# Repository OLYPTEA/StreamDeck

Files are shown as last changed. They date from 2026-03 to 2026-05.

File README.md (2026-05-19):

# KORE DECK

<p align="center">
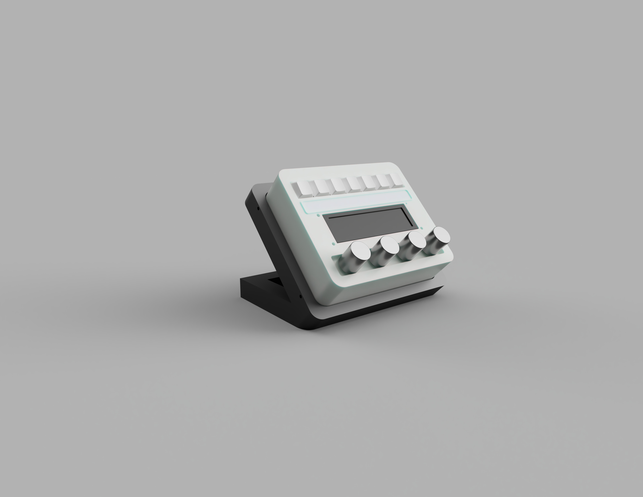
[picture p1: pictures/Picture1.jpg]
  
</p>

<p align="center">
  
  
  
</p>

<h3 align="center">
Un Hub de Control Modulaire pour PC et Robotique/A Modular Stream Deck & Robotics Control Hub (cf : Robotic_Arm)
</h3>

---

##  Video de présentation/Cinematic Demo

https://github.com/user-attachments/assets/3f7520e6-ee07-4d92-a84f-97e8f2b0d568

<p align="center">
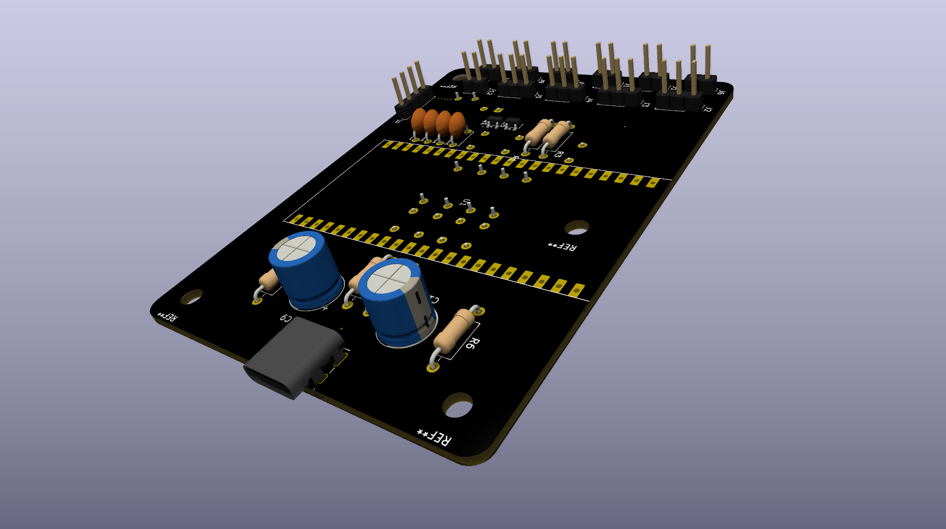
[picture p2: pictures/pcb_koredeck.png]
  
</p>

---

## Description

Ce projet est un **Stream Deck DIY** développé dans le but d'être modulaire.  
Conçu autour d'un **ESP32-S3**, il permet de piloter des raccourcis PC, de monitorer des ressources, mais aussi de servir de **Hub de contrôle** pour des périphériques externes (bras robotique, capteurs) via un port d'extension dédié.

This project is a **DIY Stream Deck** designed to be modular.  
Built around an **ESP32-S3**, it allows you to control PC shortcuts, monitor system resources, and serve as a **control hub** for external devices (such as robotic arms and sensors) via a dedicated expansion port.

---

# Spécifications Matérielles

| Composant | Détails |
| :--- | :--- |
| **Microcontrôleur** | ESP32-S3 DevKit N16R8 (16MB Flash / 8MB PSRAM) |
| **Écran** | DWIN HMI 960x240 (Interface UART, protocole DGUS II) |
| **Capteurs** | 7x Switchs mécaniques (Cherry MX) + 4x Potentiomètres analogiques |
| **Alimentation** | USB-C natif (Compatible **Thunderbolt** pour forte puissance) |
| **Modularité** | Boîtier CAO avec pied indépendant et port d'extension I2C |

---

# Points Forts du Projet

## 1. Conception Modulaire (CAO)

Le boîtier a été conçu sous **Fusion 360** avec une approche modulaire :

- **Pied indépendant :**  
  Permet d'adapter différents angles ou supports (pince de bureau, bras articulé).

- **Port d'extension :**  
  Sortie des ports non-utilisés (SDA/SCL, 5V, GND) sur le côté pour connecter des modules sans ouvrir le boîtier.

- **Modularité du Software/Firmware**
  Pensé dans le but d'être mobile et évolutif (rajout facile à intégrer)

The Case was designed in **Fusion 360** using a modular approach:

- **Detachable stand:**  
  Allows for different angles or mounts (desk clamp, articulated arm).

- **Expansion port:**  
  Unused ports (SDA/SCL, 5V, GND) are routed to the side to connect modules without opening the enclosure.

- **Software/Firmware Modularity**
  Designed to be portable and scalable (easy to integrate new features)

---

## 2. Hub Robotique/Robotics Hub

Grâce au port d'extension, le Stream Deck peut piloter un **bras robotique** (servomoteurs) via un driver **PCA9685**.

- **Mapping dynamique :**  
  Les potentiomètres contrôlent directement les angles des servos lorsque le profil `Robot` est sélectionné.

- **Affichage temps réel :**  
  L'écran DWIN affiche l'état et la position de chaque articulation.

Thanks to the expansion port, the Stream Deck can control a **robotic arm** (servo motors) via a **PCA9685** driver.

- **Dynamic mapping:**  
  The potentiometers directly control the servo angles when the `Robot` profile is selected.

- **Real-time display:**  
  The DWIN screen displays the status and position of each joint.

---

## 3. Gestion de l'Énergie/Energy Management

Optimisation pour le **Thunderbolt** :

- Alimentation directe des périphériques (Écran, Servos) via la ligne **5V/Vin** pour préserver le régulateur interne de l'ESP32.

- Filtrage matériel par condensateurs (`470µF` → `1000µF`) pour stabiliser les pics de courant des moteurs.

Optimization for **Thunderbolt**:

- Direct power supply to peripherals (display, servos) via the **5V/Vin** line to preserve the ESP32’s internal voltage regulator.

- Hardware filtering using capacitors (`470µF` → `1000µF`) to stabilize motor current spikes.

---

# Schéma de Câblage (Résumé)/Wiring Diagram (Summary)

Le projet utilise des techniques de filtrage pour garantir la précision des lectures analogiques :

- **Potentiomètres :**  
  Condensateurs de `100nF` pour le lissage du signal.

- **Boutons :**  
  Condensateurs de `10nF` pour le debounce matériel.

- **Communication Écran :**  
  Liaison série directe (`3.3V TTL`) sur `Rx2/Tx2`.

The project uses filtering techniques to ensure the accuracy of analog readings:

- **Potentiometers:**  
  `100nF` capacitors for signal smoothing.

- **Buttons:**  
  `10nF` capacitors for hardware debouncing.

- **Display communication:**  
  Direct serial connection (`3.3V TTL`) on `Rx2/Tx2`.

---

# Structure du Dépôt/Structure of the Repository

```text
├── Hardware/           # Fichiers STEP/STL (Fusion 360)/STEP/STL files (Fusion 360)
├── Firmware/           # Code source ESP32 (Arduino IDE / PlatformIO)/ESP32 source code (Arduino IDE / PlatformIO)
├── DWIN_Project/       # Fichiers de configuration DGUS II (Interface graphique)/DGUS II Configuration Files (Graphical Interface)
├── Scripts_PC/         # Script de détection d'application (Python/C#)/Application detection script (Python/C#)
└── Assets/             # Icônes, vidéos et ressources graphiques/Icons, videos, and graphic resources
```

---

# Roadmap

- [ ] Interface UI avancée/Advanced UI (check)
- [ ] Gestion multi-profils/Multi-profile management (check)
- [ ] Intégration MQTT/MQTT integration
- [ ] Contrôle robotique avancé/Advanced robotics control
- [ ] Support Wi-Fi / Bluetooth/Wi-Fi / Bluetooth support
- [ ] Intégration Home Assistant/Home Assistant integration

---

# Technologies Utilisées/Technologies Used

- **ESP32-S3**
- **DGUS II / DWIN HMI**
- **Fusion 360**
- **Arduino / PlatformIO**
- **Python / C++**
- **I2C / UART**
- **KicKad**

---

# Auteur/Author

Projet conçu et développé par **OLYPTEA** (Sacha Gibert).

Project designed and developed by **OLYPTEA** (Sacha Gibert).

GitHub :  
https://github.com/OLYPTEA

---

Mention à Andrei Doncescu : https://homepages.laas.fr/adoncesc/SystemEmbed/Filtrage.pdf, 
          Random Nerds Tutorial : https://randomnerdtutorials.com/esp32-save-data-permanently-preferences/, 
          cppreference.com : https://en.cppreference.com/cpp/language/static_cast,
          Peng Zhihui : https://github.com/peng-zhihui/HoloCubic <3,
          STMicroelectronics — AN2834 : https://www.st.com/resource/en/application_note/cd00211314-how-to-optimize-the-adc-accuracy-in-the-stm32-mcus-stmicroelectronics.pdf,
          Claude code : Débogage,
          Espressif Systems : https://documentation.espressif.com/esp32-s3_datasheet_en.pdf,
          Tauri : http://github.com/tauri-apps/tauri/blob/dev/ARCHITECTURE.md,
                  https://github.com/tauri-apps/awesome-tauri

---

Merci d'avoir pris le temps de regarder le projet

Thank you for taking the time to look at the project

---

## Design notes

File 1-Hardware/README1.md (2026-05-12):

# Avertissement / Warning :

## FR : L'empreinte de l'ESP32 utilisée dans la schématique n'est pas la bonne, il s'agit de l'empreinte d'un ESP32-S3-WROOM-1 (utilisé pour des raisons de praticité dans le logiciel) -> Impact sur les GPIO utilisés : RX0 = GPIO 16 et TX0 = GPIO 17 , Switchs (1/7) =  GpIO 09, GPIO 08, GPIO 14, GPIO 13, GPIO 15, GPIO 12, GPIO 11 (Correct dans le schéma), Potentiomètres = GPIO 04, GPIO 05, GPIO 06, GPIO 07

## ENG : The ESP32 footprint used in the schematic is incorrect, it's the footprint of an ESP32-S3-WROOM-1 (used for convenience in the software). This impacts the GPIO pins used : RX0 = GPIO 16 and TX0 = GPIO 17, Switches (1/7) = GPIO 9, GPIO 8, GPIO 14, GPIO 13, GPIO 15, GPIO 12, GPIO 11 (Correct in the schematic), Potentiometers = GPIO 4, GPIO 5, GPIO 6, GPIO 7

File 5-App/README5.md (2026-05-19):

# Kore Deck — Application Desktop

Application Tauri 2 (Rust + WebView2) qui sert d'interface de contrôle pour Kore Deck.
Elle se connecte à l'agent Python via WebSocket et affiche en temps réel les données système,
les actions boutons et les valeurs potentiomètres.

---

## Stack technique

| Couche | Technologie | Version |
|---|---|---|
| Shell natif | Tauri | 2.x |
| Backend Rust | Tauri core + serialport + env_logger | — |
| Frontend | React + TypeScript | 19 / 5.x |
| Bundler | Vite | 7.x |
| State management | Zustand (persist → localStorage) | 5.x |
| Transport | WebSocket `ws://localhost:8765` | — |
| Design system | Carbon (custom CSS, palette `#0C0C0E`) | — |

---

## Prérequis

| Outil | Version minimale | Vérification |
|---|---|---|
| Node.js | 20 LTS | `node -v` |
| npm | 10+ | `npm -v` |
| Rust (stable) | 1.82 | `rustc --version` |
| WebView2 Runtime | — | préinstallé sur Win 11 , sinon [télécharger](https://developer.microsoft.com/fr-fr/microsoft-edge/webview2/) |
| Python | 3.10+ | `python --version` |

> **Windows uniquement.** Le binaire final est un `.exe` / `.msi` ciblant Windows 10/11 x64.

---

## Installation des dépendances

```bash
# Depuis le dossier Kore Deck/KoreDeck_App/
npm install
```

Cargo télécharge automatiquement les crates Rust au premier build.

---

## Développement

### 1. Mode Dev (si vous voulez bricoler :D )

```bash
# Terminal 1 — app Tauri 
npm run tauri dev
```

Une fenêtre s'ouvre avec le hot-reload Vite actif.
Le simulateur de données (`useDevSimulator`) s'active automatiquement **uniquement** en mode dev
(`import.meta.env.DEV`) : il injecte des stats CPU/RAM fictives toutes les secondes,
ce code est absent du build final.

### 2. Lancer l'agent Python en parallèle (optionnel en dev)

```bash
# Terminal 2 — depuis Software/
python agent.py --port COM3 --baud 115200
```

Sans l'agent, le simulateur dev prend le relais pour les métriques.
Avec l'agent, la connexion WebSocket `ws://localhost:8765` est établie automatiquement.

---

## Build de production

```bash
npm run tauri build
```

Durée typique : 4–8 min (première fois, Cargo compile tout).

### Artefacts générés

| Fichier | Chemin |
|---|---|
| Exécutable portable | `src-tauri/target/release/kore-deck.exe` |
| Installateur MSI | `src-tauri/target/release/bundle/msi/kore-deck_*.msi` |
| Installateur NSIS | `src-tauri/target/release/bundle/nsis/kore-deck_*-setup.exe` |

---

## Architecture du code frontend

```
src/
├── App.tsx               # Routage principal + hook useDevSimulator (dev only)
├── index.css             # Design system Carbon — variables CSS globales
│
├── components/
│   ├── Sidebar.tsx       # Navigation latérale + indicateur de connexion
│   ├── Dashboard.tsx     # Vue HOME — CPU, RAM, pistes audio
│   ├── Settings.tsx      # Configuration port série, WebSocket, reconnexion
│   └── Profiles.tsx      # Sélection de catégorie (HOME / MAKING / FOCUS / GAME)
│
├── hooks/
│   └── useSerial.ts      # Connexion WebSocket, parsing trames, reconnexion auto
│
└── store/
    └── useStore.ts       # Zustand store — état global + persist localStorage
```

---

## Flux de données

```
ESP32-S3 (UART 115200)
    │  trames texte : "POT:VOL_MASTER:87", "ACTION:MUTE", "CAT:2"
    ▼
Agent Python  (Software/agent.py)
    │  WebSocket JSON  ws://localhost:8765
    ▼
useSerial.ts  (hook React)
    │  messages parsés → dispatch Zustand
    ▼
Zustand store  (useStore.ts)
    │  état réactif : stats, connexion, settings
    ▼
Composants React  (Dashboard, Sidebar, Settings, Profiles)
```

---

## Commandes Tauri (Rust → frontend)

| Commande | Description |
|---|---|
| `list_serial_ports` | Renvoie la liste des ports COM disponibles |
| `open_serial` | Ouvre un port série (port, baud) |
| `close_serial` | Ferme le port série actif |
| `send_serial` | Envoie une trame brute sur le port ouvert |
| `read_serial` | Lit les octets disponibles |
| `get_app_version` | Renvoie la version depuis `Cargo.toml` |
| `show_in_explorer` | Ouvre l'explorateur sur un chemin donné |
| `get_log_path` | Renvoie le chemin du fichier de log actif |

---

## Paramètres de connexion par défaut

| Paramètre | Valeur |
|---|---|
| Port série | `COM3` |
| Baud rate | `115200` |
| WebSocket | `ws://localhost:8765` |
| Reconnexion auto | activée, délai 3 s |
| Timeout PC (firmware) | 5 000 ms |

Ces valeurs sont modifiables dans l'onglet **Settings** et persistent au redémarrage.

---

## Persistance des données

L'état de l'application est sauvegardé via Zustand `persist` dans le `localStorage` du WebView2.

| Clé localStorage | `kore-deck-store` |
|---|---|
| Chemin physique (Windows) | `%APPDATA%\com.koredeck.deck\EBWebView\Default\Local Storage\` |
| Contenu | settings (port, baud, ws URL), catégorie active, préférences UI |

Pour réinitialiser : supprimer la clé dans les DevTools (F12 → Application → Local Storage).

---

## Lancer les DevTools en production

La fenêtre Tauri expose les DevTools uniquement en mode dev.
Pour déboguer un build release, ajouter temporairement dans `tauri.conf.json` :

```json
"app": {
  "windows": [{ "devtools": true }]
}
```

---

## Régénérer depuis zéro (environnement vierge)

```bash
# 1. Installer Rust
curl --proto '=https' --tlsv1.2 -sSf https://sh.rustup.rs | sh   # Linux/macOS
# ou : https://rustup.rs  (Windows)

# 2. Installer les cibles Tauri
cargo install tauri-cli --version "^2"

# 3. Installer Node.js 20 LTS : https://nodejs.org

# 4. Cloner le projet
git clone <repo-url>
cd Kore Deck/5-App

# 5. Dépendances Node
npm install

# 6. Dev
npm run tauri dev

# 7. Production
npm run tauri build
```

---

## Dépannage

| Symptôme | Cause probable | Solution |
|---|---|---|
| Fenêtre blanche au démarrage | WebView2 absent | Installer [WebView2 Runtime](https://developer.microsoft.com/fr-fr/microsoft-edge/webview2/) |
| `error: linker 'link.exe' not found` | MSVC non installé | Installer **Build Tools for Visual Studio 2022** avec la charge « Développement Desktop C++ » |
| WebSocket ne se connecte pas | Agent Python non démarré | Lancer `python agent.py` en parallèle |
| Port COM introuvable | Pilote USB absent | Installer le pilote CP210x ou CH340 selon la puce USB-UART de la carte |
| `SERIAL_BUFFER_SIZE` overflow (firmware) | Trame corrompue trop longue | Vérifier câble USB, réduire longueur trame, redémarrer ESP32 |

**Bonne utilisation à tous, si vous trouvez un bug ou des trucs à optimiser n'hesitez pas à demander un pull request, HF :D**

---

Auteur : OLYPTEA

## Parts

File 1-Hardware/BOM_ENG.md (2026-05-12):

# BOM - ESP32-S3 Stream Deck / Control Panel

## Microcontroller
| Quantity | Component | Reference |
|---|---|---|
| 1 | ESP32-S3 DevKit | ESP32-S3 DevKit N16R8 |

---

## User Interface

### Potentiometers
| Quantity | Component | Value |
|---|---|---|
| 4 | Linear Potentiometer | B10K |

### Mechanical Switches
| Quantity | Component | Reference |
|---|---|---|
| 7 | Mechanical Keyboard Switch | Cherry MX |

### Display
| Quantity | Component | Reference |
|---|---|---|
| 1 | DWIN Display | DMG96240C037_03W |

---

## Transistors
| Quantity | Component | Reference |
|---|---|---|
| 2 | N-Channel MOSFET | BSS138 |

---

## Capacitors
| Quantity | Component | Value |
|---|---|---|
| 7 | Ceramic Capacitor | 10nF |
| 5 | Ceramic Capacitor | 100nF |
| 1 | Electrolytic Capacitor | 10µF |

---

## Resistors
| Quantity | Component | Value |
|---|---|---|
| 4 | Resistor | 10kΩ |
| 4 | Resistor | 1kΩ |
| 2 | Resistor | 5.1kΩ |

---

## Connectivity
| Quantity | Component | Reference |
|---|---|---|
| 1 | USB Type-C Connector | USB-C Port |

---

# Notes
- The 5.1kΩ resistors are used for USB-C CC1/CC2 configuration.
- The 100nF capacitors are used for power supply decoupling.
- The BSS138 MOSFETs are be used for logic level shifting (5V to 3.3V).
- The DWIN display generally communicates with the ESP32-S3 through UART.

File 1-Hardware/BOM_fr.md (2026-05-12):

# BOM - ESP32-S3 Stream Deck / Control Panel

## Microcontrôleur
| Quantité | Composant | Référence |
|---|---|---|
| 1 | ESP32-S3 DevKit | ESP32-S3 DevKit N16R8 |

---

## Interface utilisateur

### Potentiomètres
| Quantité | Composant | Valeur |
|---|---|---|
| 4 | Potentiomètre linéaire | B10K |

### Switchs mécaniques
| Quantité | Composant | Référence |
|---|---|---|
| 7 | Switch mécanique Cherry MX | Cherry MX |

### Écran
| Quantité | Composant | Référence |
|---|---|---|
| 1 | Écran DWIN | DMG96240C037_03W |

---

## Transistors
| Quantité | Composant | Référence |
|---|---|---|
| 2 | MOSFET N-Channel | BSS138 |

---

## Condensateurs
| Quantité | Composant | Valeur |
|---|---|---|
| 7 | Condensateur céramique | 10nF |
| 5 | Condensateur céramique | 100nF |
| 1 | Condensateur électrolytique | 10µF |

---

## Résistances
| Quantité | Composant | Valeur |
|---|---|---|
| 4 | Résistance | 10kΩ |
| 4 | Résistance | 1kΩ |
| 2 | Résistance | 5.1kΩ |

---

## Connectique
| Quantité | Composant | Référence |
|---|---|---|
| 1 | Connecteur USB Type-C | USB-C Port |

---

# Notes
- Les résistances 5.1kΩ sont utilisées pour la configuration CC1/CC2 du port USB-C.
- Les condensateurs 100nF servent au découplage de l’alimentation.
- Les BSS138 peuvent sont utilisés pour du level shifting (L'écran DWIN communique en 5v et l'ESP32-S3 en 3.3V).
- L’écran DWIN communique via UART avec l’ESP32-S3.

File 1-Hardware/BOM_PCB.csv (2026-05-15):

Reference | Qty | Value | DNP | Exclude from BOM | Exclude from Board | Footprint | Datasheet
C1,C2,C3,C4 | 4 | 100nF |  |  |  | Capacitor_THT:C_Disc_D5.0mm_W2.5mm_P5.00mm
C5,C6,C7,C8,C10,C11 | 6 | 10nF |  |  |  | Capacitor_THT:C_Disc_D5.0mm_W2.5mm_P5.00mm
C9,C14 | 2 | 100nF |  |  |  | Capacitor_THT:CP_Radial_D8.0mm_P3.50mm
C12 | 1 | C |  |  |  | Capacitor_THT:C_Disc_D5.0mm_W2.5mm_P5.00mm
C13 | 1 | 10µF |  |  |  | Capacitor_THT:CP_Radial_D8.0mm_P3.50mm
J1 | 1 | Conn_01x04_Pin |  |  |  | Connector_PinHeader_2.54mm:PinHeader_1x04_P2.54mm_Vertical
J2,J3,J4,J5 | 4 | Conn_01x03_Pin |  |  |  | Connector_PinHeader_2.54mm:PinHeader_1x03_P2.54mm_Vertical
J6,J7,J8,J9,J10,J11,J12 | 7 | Conn_01x02_Pin |  |  |  | Connector_PinHeader_2.54mm:PinHeader_1x02_P2.54mm_Vertical
P1 | 1 | USB_C_Plug_USB2.0 |  |  |  | Connector_USB:USB_C_Receptacle_GCT_USB4085 | https://www.usb.org/sites/default/files/documents/usb_type-c.zip
Q1,Q2 | 2 | BSS138 |  |  |  | Package_TO_SOT_SMD:SOT-23 | https://www.onsemi.com/pub/Collateral/BSS138-D.PDF
R1,R2,R3,R4 | 4 | 10k |  |  |  | Resistor_THT:R_Axial_DIN0207_L6.3mm_D2.5mm_P10.16mm_Horizontal
R5,R6 | 2 | 5.1K |  |  |  | Resistor_THT:R_Axial_DIN0207_L6.3mm_D2.5mm_P10.16mm_Horizontal
R7,R8,R9,R10 | 4 | 1k |  |  |  | Resistor_THT:R_Axial_DIN0207_L6.3mm_D2.5mm_P10.16mm_Horizontal
R11,R12 | 2 | 22Ω |  |  |  | Resistor_THT:R_Axial_DIN0207_L6.3mm_D2.5mm_P10.16mm_Horizontal
U1 | 1 |  |  |  |  | ESP32:Sans titre
U2 | 1 | USBLC6-2SC6 |  |  |  | Package_TO_SOT_SMD:SOT-23-6 | https://www.st.com/resource/en/datasheet/usblc6-2.pdf

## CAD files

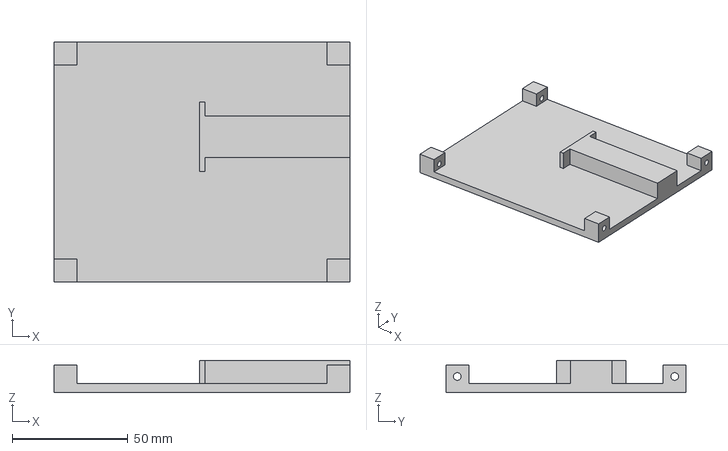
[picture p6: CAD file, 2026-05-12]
4-Modele/KORE_DECK_Plate.step
128.0 x 104.0 x 14.0 mm

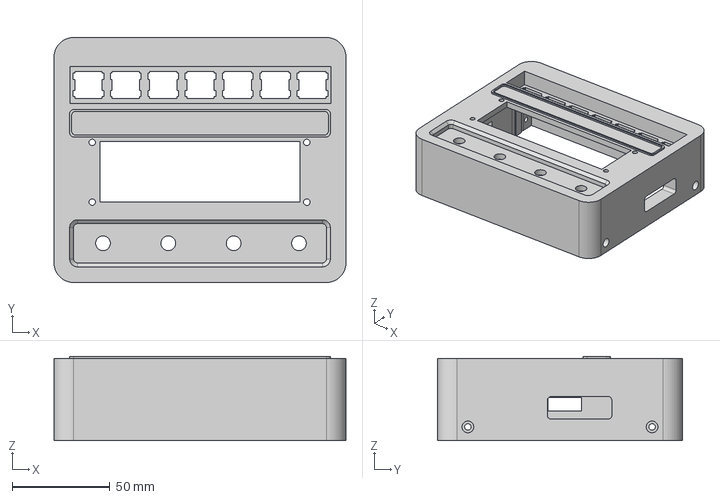
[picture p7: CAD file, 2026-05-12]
4-Modele/KORE_DECK_CASE.step
149.0 x 125.0 x 43.0 mm

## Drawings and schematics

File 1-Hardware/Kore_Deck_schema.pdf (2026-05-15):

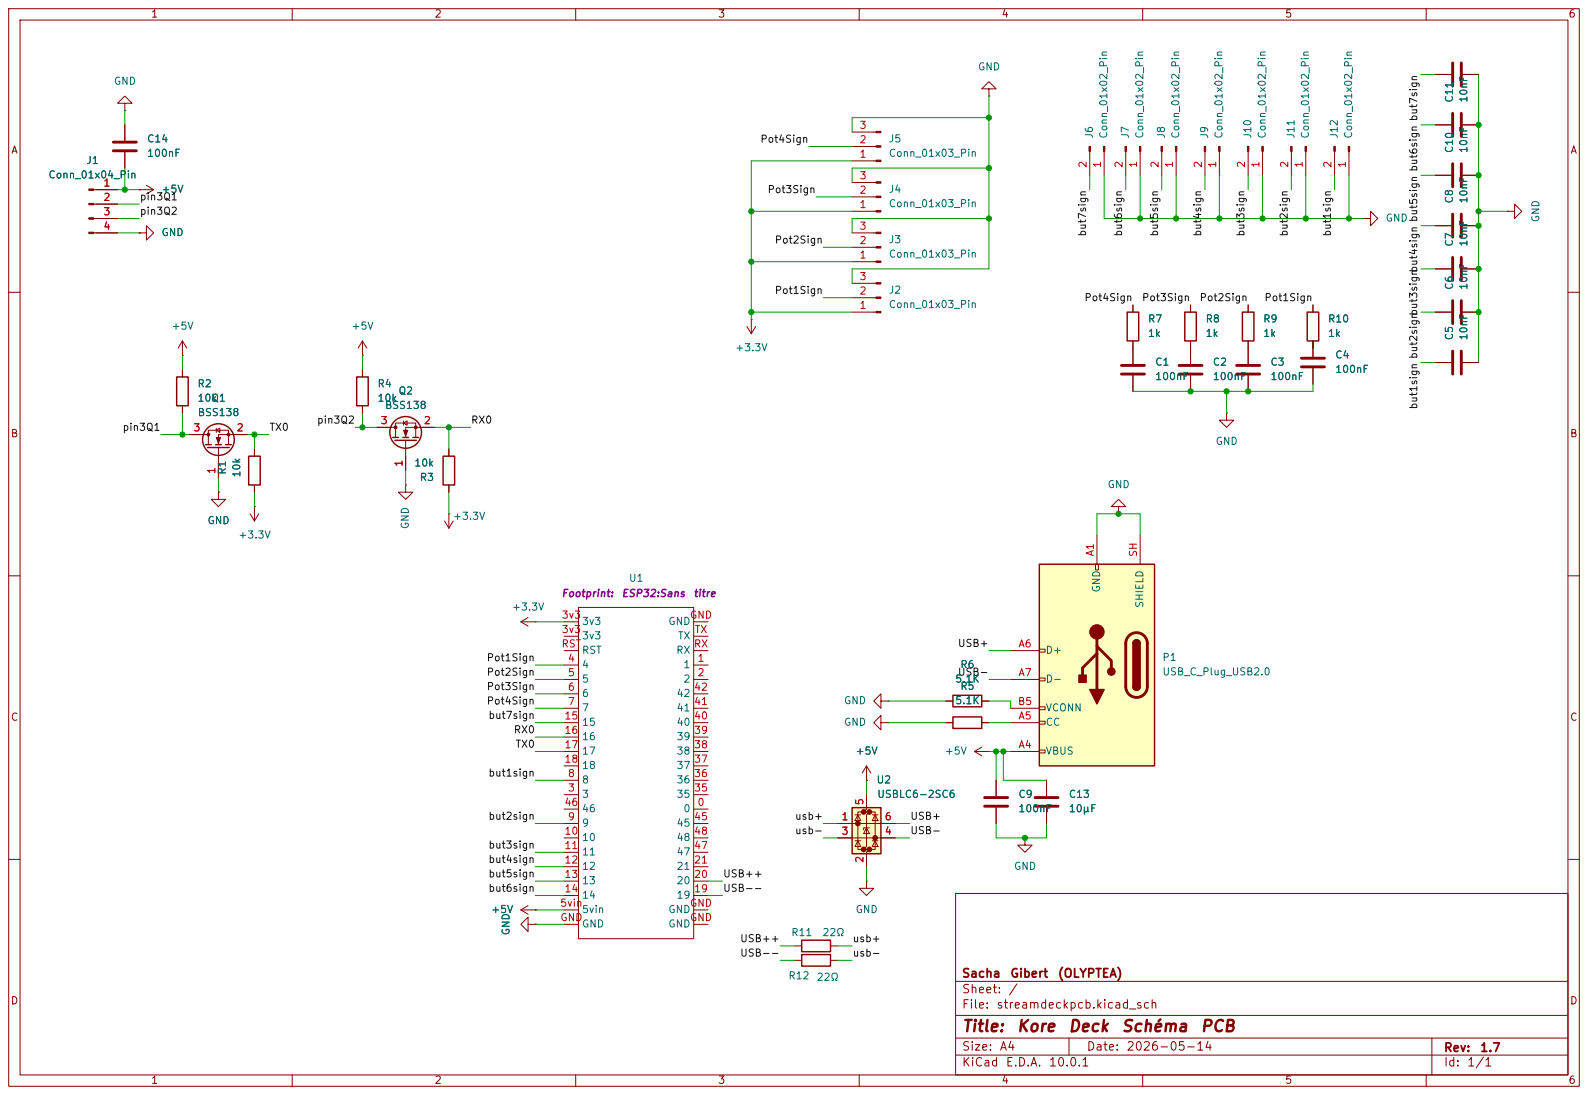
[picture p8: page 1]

Sacha Gibert (OLYPTEA)
Sheet: /
File: streamdeckpcb.kicad_sch
Title: Kore Deck Schéma PCB

Size: A4 | Rev: 1.7
KiCad E.D.A. 10.0.1 | Id: 1/1

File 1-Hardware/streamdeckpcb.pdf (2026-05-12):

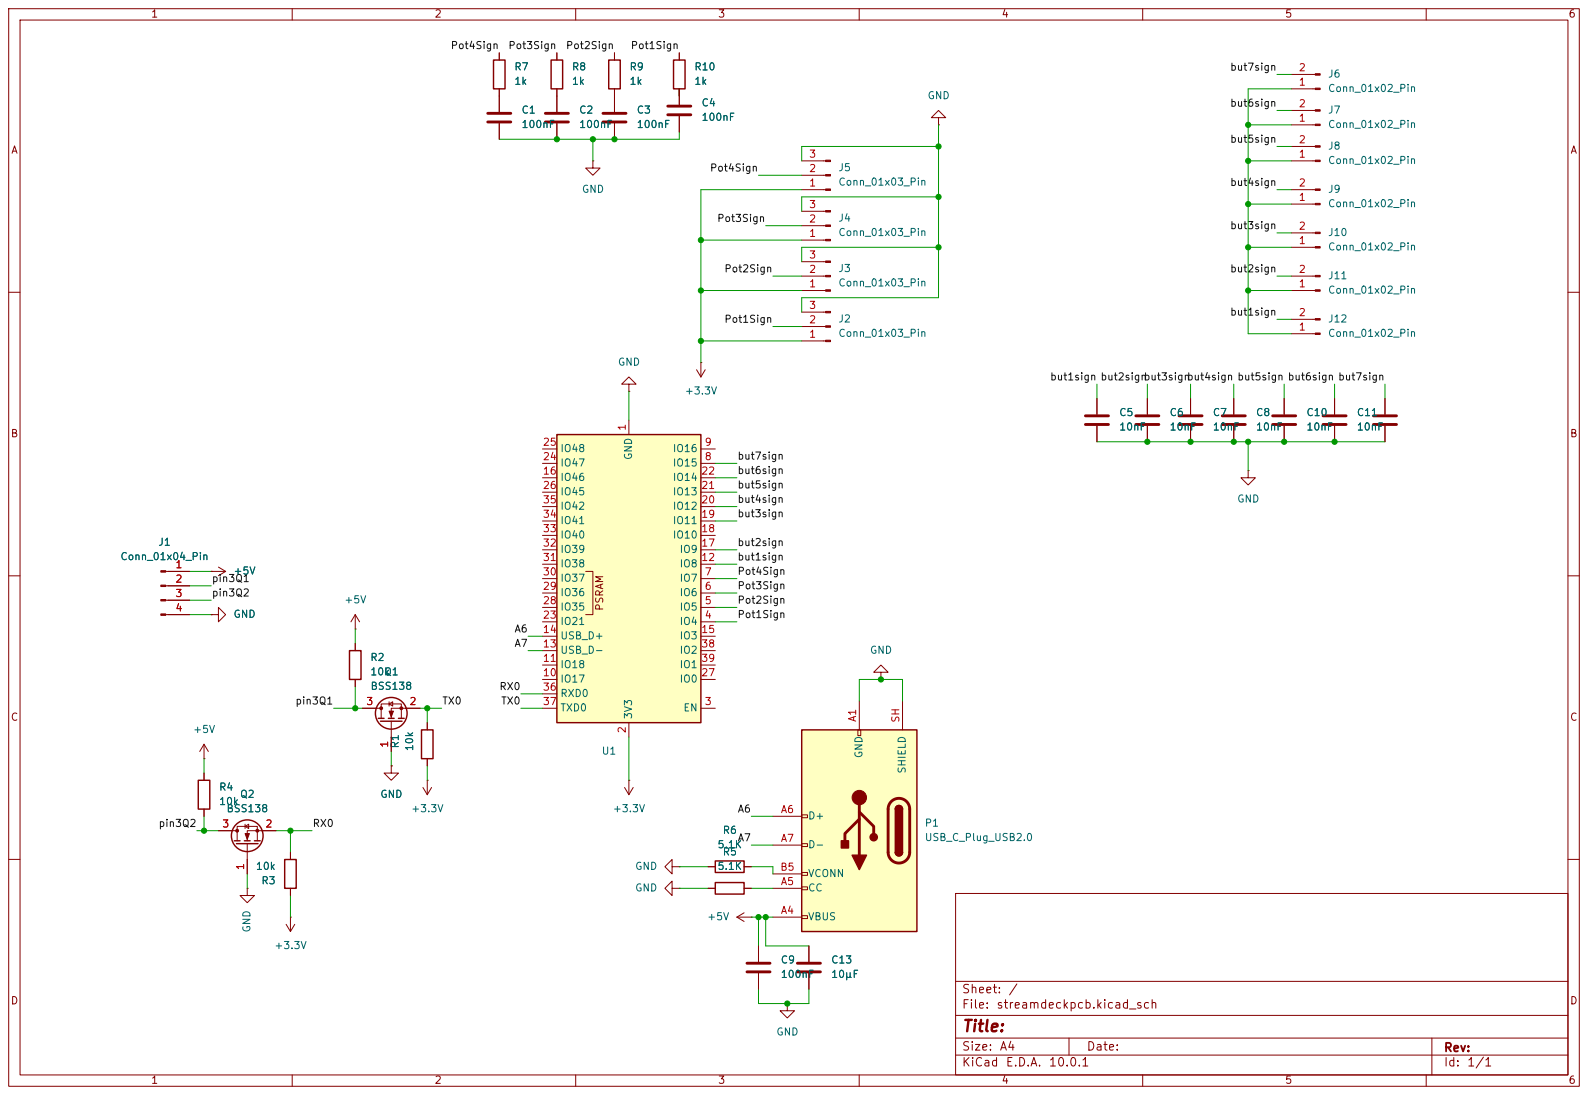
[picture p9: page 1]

Size: A4 | Rev:
KiCad E.D.A. 10.0.1 | Id: 1/1

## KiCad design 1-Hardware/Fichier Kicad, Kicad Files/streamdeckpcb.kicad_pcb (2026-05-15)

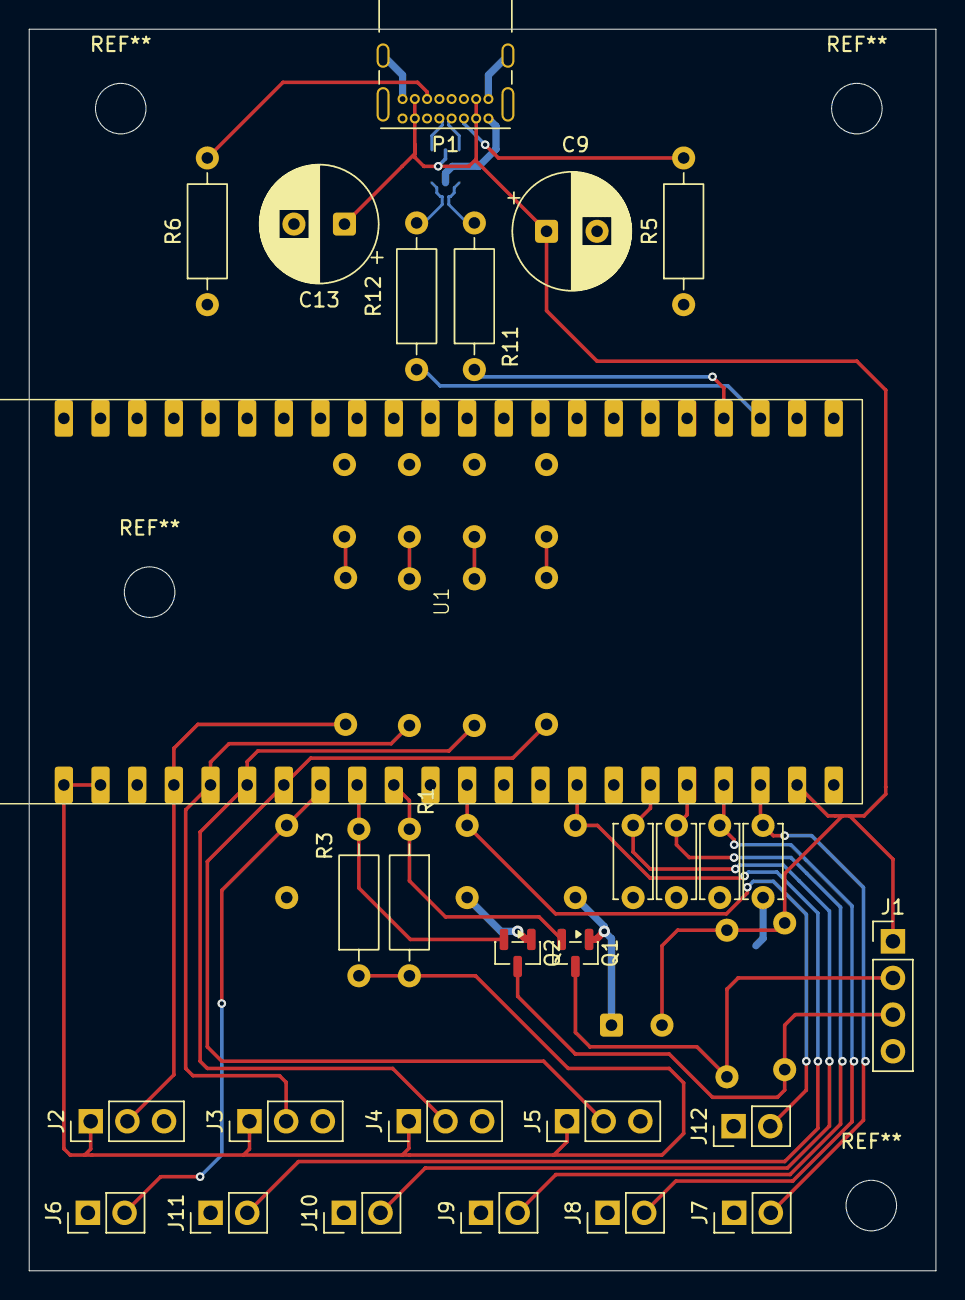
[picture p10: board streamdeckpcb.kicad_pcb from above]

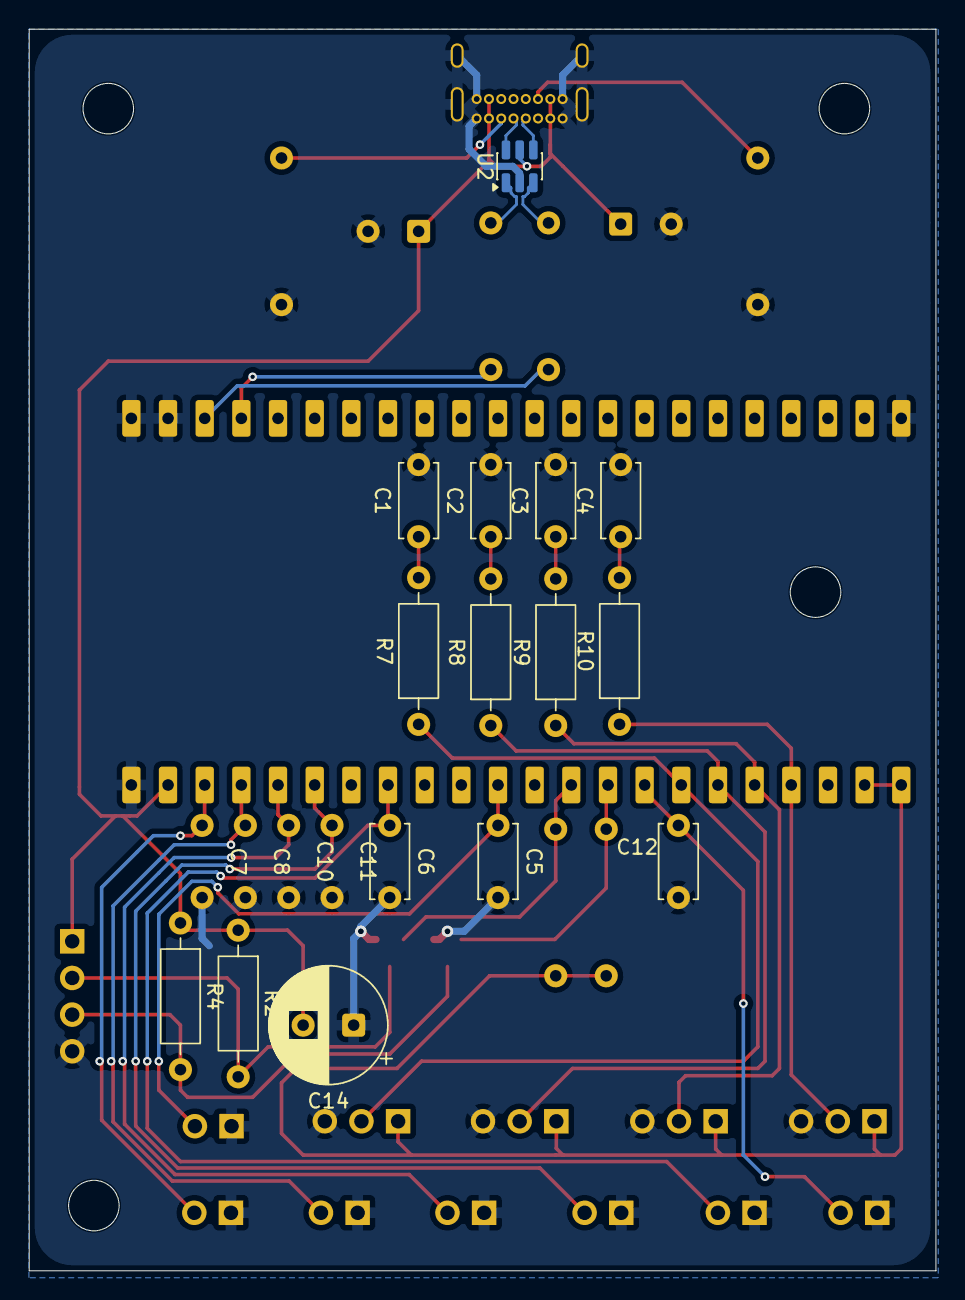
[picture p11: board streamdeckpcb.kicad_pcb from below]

Board: 2 copper layers, 62.8 x 86.0 mm, 43 parts (15 on the bottom side), 30 nets.

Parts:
C1, C2, C3, C4: 100nF; C_Disc_D5.0mm_W2.5mm_P5.00mm
C5, C6, C7, C8, C10, C11: 10nF; C_Disc_D5.0mm_W2.5mm_P5.00mm
C9, C14: 100nF; CP_Radial_D8.0mm_P3.50mm
C12: C; C_Disc_D5.0mm_W2.5mm_P5.00mm
C13: 10µF; CP_Radial_D8.0mm_P3.50mm
J1: dwin; PinHeader_1x04_P2.54mm_Vertical
J2: pot1; PinHeader_1x03_P2.54mm_Vertical
J3: pot2; PinHeader_1x03_P2.54mm_Vertical
J4: pot3; PinHeader_1x03_P2.54mm_Vertical
J5: pot4; PinHeader_1x03_P2.54mm_Vertical
J6, J11: but7; PinHeader_1x02_P2.54mm_Vertical
J7: but6; PinHeader_1x02_P2.54mm_Vertical
J8: but5; PinHeader_1x02_P2.54mm_Vertical
J9, J10: but3; PinHeader_1x02_P2.54mm_Vertical
J12: but1; PinHeader_1x02_P2.54mm_Vertical
P1: USB_C_Plug_USB2.0; USB_C_Receptacle_GCT_USB4085
Q1, Q2: BSS138; SOT-23
R1, R2, R3, R4: 10k; R_Axial_DIN0207_L6.3mm_D2.5mm_P10.16mm_Horizontal
R5, R6: 5.1K; R_Axial_DIN0207_L6.3mm_D2.5mm_P10.16mm_Horizontal
R7, R8, R9, R10: 1k; R_Axial_DIN0207_L6.3mm_D2.5mm_P10.16mm_Horizontal
R11, R12: 22Ω; R_Axial_DIN0207_L6.3mm_D2.5mm_P10.16mm_Horizontal
U1: Sans titre
U2: USBLC6-2SC6; SOT-23-6

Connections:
+3.3V: J2.1, J3.1, J4.1, J5.1, R1.2, R3.1, U1.3v3
+5V: C9.1, C13.1, C14.2, J1.1, P1.A4 (VBUS), P1.A9 (VBUS), P1.B4 (VBUS), P1.B9 (VBUS), R2.1, R4.1, U1.5vin, U2.5 (VBUS)
/Pot1Sign: J2.2, R10.1, U1.4
/Pot2Sign: J3.2, R9.1, U1.5
/Pot3Sign: J4.2, R8.1, U1.6
/Pot4Sign: J5.2, R7.1, U1.7
/RX0: Q2.2 (S), R3.2, U1.16
/TX0: Q1.2 (S), R1.1, U1.17
/USB+: P1.A6 (D+), U2.6 (I/O1)
/USB++: R11.1, U1.20
/USB-: P1.A7 (D-), U2.4 (I/O2)
/USB--: R12.1, U1.19
/but1sign: C5.1, J12.2, U1.8
/but2sign: C6.1, J11.2, U1.9
/but3sign: C7.1, J10.2, U1.11
/but4sign: C8.1, J9.2, U1.12
/but5sign: C10.1, J8.2, U1.13
/but6sign: C11.1, J7.2, U1.14
/but7sign: C12.1, J6.2, U1.15
/pin3Q1: J1.2, Q1.3 (D), R2.2
/pin3Q2: J1.3, Q2.3 (D), R4.2
/usb+: R11.2, U2.1 (I/O1)
/usb-: R12.2, U2.3 (I/O2)
GND: C1.2, C2.2, C3.2, C4.2, C5.2, C6.2, C7.2, C8.2, C9.2, C10.2, C11.2, C12.2, C13.2, C14.1, J1.4, J2.3, J3.3, J4.3, J5.3, J6.1, J7.1, J8.1, J9.1, J10.1, J11.1, J12.1, P1.A1 (GND), P1.A12 (GND), P1.B1 (GND), P1.B12 (GND), P1.SH (SHIELD), Q1.1 (G), Q2.1 (G), R5.1, R6.1, U1.GND, U2.2 (GND)
unnamed: C1.1, R7.2
unnamed: C2.1, R8.2
unnamed: C3.1, R9.2
unnamed: C4.1, R10.2
unnamed: P1.A5 (CC), R5.2
unnamed: P1.B5 (VCONN), R6.2

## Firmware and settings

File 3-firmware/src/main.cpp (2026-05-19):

// =============================================================================
// main.cpp — Kore Deck — Firmware principal
//
// Matériel : ESP32-S3-DevKitC-1 N16R8
// Auteur   : OLYPTEA (Sacha Gibert) - https://github.com/OLYPTEA
//
// Architecture :
//   - setup()        : initialisation matérielle + restauration état NVS 
//   - loop()         : orchestration des tâches périodiques
//   - handlePots()   : acquisition et envoi des potentiomètres
//   - handleButtons(): détection événements boutons
//   - handleSerial() : réception/parsing des trames PC
//   - updateDisplay(): mise à jour de l'écran DWIN
//   - enterCategory(): transition de catégorie
// =============================================================================

#include <Arduino.h>
#include <esp_task_wdt.h>

#include "config.h"
#include "pot.h"
#include "button.h"
#include "dwin.h"
#include "protocol.h"
#include "nvs_manager.h"

// ─────────────────────────────────────────────────────────────────────────────
// Instances globales
// ─────────────────────────────────────────────────────────────────────────────
static Potentiometer pots[POT_COUNT] = {
    Potentiometer(PIN_POT_1, 0),
    Potentiometer(PIN_POT_2, 1),
    Potentiometer(PIN_POT_3, 2),
    Potentiometer(PIN_POT_4, 3)
};

static Button buttons[BTN_COUNT] = {
    Button(PIN_BTN[0], 0), Button(PIN_BTN[1], 1),
    Button(PIN_BTN[2], 2), Button(PIN_BTN[3], 3),
    Button(PIN_BTN[4], 4), Button(PIN_BTN[5], 5),
    Button(PIN_BTN[6], 6)
};

static DwinDisplay  display;
static NVSManager   nvs;
static PCData       pcData;
static Category     currentCategory = Category::HOME;

// Buffer de réception série
static char    serialBuf[SERIAL_BUFFER_SIZE];
static uint16_t serialBufIdx = 0;

// Timings
static uint32_t lastPotSampleTime   = 0;
static uint32_t lastPCReceiveTime   = 0;
static bool     pcConnected         = false;

// ─────────────────────────────────────────────────────────────────────────────
// Prototypes
// ─────────────────────────────────────────────────────────────────────────────
static void     handlePots();
static void     handleButtons();
static void     handleSerial();
static void     updateDisplay();
static void     enterCategory(Category cat);
static void     sendAction(const char* action);
static void     sendPotEvent(uint8_t potIdx, uint8_t value);
static void     checkPCConnection();
static void     initWatchdog();

// ─────────────────────────────────────────────────────────────────────────────
// setup()
// ─────────────────────────────────────────────────────────────────────────────
void setup() {
    // --- USB CDC natif (déjà actif grâce aux build_flags)
    Serial.begin(115200);
    delay(500); // Attente énumération USB

    Serial.println(F("[StreamDeck] Boot v2.0"));

    // --- Watchdog hardware
    initWatchdog();

    // --- ADC configuration (ESP32-S3)
    analogSetAttenuation(ADC_11db);      // Plage 0-3.3V
    analogReadResolution(12);            // 12 bits

    // --- Initialisation potentiomètres
    for (uint8_t i = 0; i < POT_COUNT; ++i) {
        pots[i].begin();
    }

    // --- Initialisation boutons
    for (uint8_t i = 0; i < BTN_COUNT; ++i) {
        buttons[i].begin();
    }

    // --- Initialisation écran DWIN
    display.begin();

    // --- Restauration catégorie NVS
    nvs.begin();
    currentCategory = nvs.loadCategory();
    nvs.end();

    // --- Page d'accueil DWIN
    display.setPage(DWIN_PAGE_HOME);
    display.updatePotLabels(currentCategory);

    // --- Signal de boot vers le PC
    Serial.println(F("READY"));

    Serial.print(F("[StreamDeck] Catégorie restaurée : "));
    Serial.println(static_cast<uint8_t>(currentCategory));
}

// ─────────────────────────────────────────────────────────────────────────────
// loop()
// ─────────────────────────────────────────────────────────────────────────────
void loop() {
    // --- Réinitialisation watchdog (preuve que la loop tourne)
    esp_task_wdt_reset();

    uint32_t now = millis();

    // --- Tâche 1 : Lecture potentiomètres (toutes les POT_SAMPLE_PERIOD_MS)
    if (now - lastPotSampleTime >= POT_SAMPLE_PERIOD_MS) {
        lastPotSampleTime = now;
        handlePots();
    }

    // --- Tâche 2 : Lecture boutons (toutes les itérations, rapide)
    handleButtons();

    // --- Tâche 3 : Réception série PC
    handleSerial();

    // --- Tâche 4 : Vérification connexion PC
    checkPCConnection();

    // --- Tâche 5 : Mise à jour affichage DWIN
    updateDisplay();
}

// ─────────────────────────────────────────────────────────────────────────────
// handlePots() — Acquisition et envoi des potentiomètres
// ─────────────────────────────────────────────────────────────────────────────
static void handlePots() {
    uint8_t potValues[POT_COUNT];
    bool    anyChanged = false;

    for (uint8_t i = 0; i < POT_COUNT; ++i) {
        if (pots[i].update()) {
            anyChanged = true;
            uint8_t catIdx = static_cast<uint8_t>(currentCategory);
            sendPotEvent(i, pots[i].getValue());
        }
        potValues[i] = pots[i].getValue();
    }

    // Mise à jour des barres de progression DWIN si au moins une valeur a changé
    if (anyChanged) {
        display.updatePotValues(potValues);
    }
}

// ─────────────────────────────────────────────────────────────────────────────
// handleButtons() — Détection et dispatch des événements boutons
// ─────────────────────────────────────────────────────────────────────────────
static void handleButtons() {
    for (uint8_t i = 0; i < BTN_COUNT; ++i) {
        ButtonEvent evt = buttons[i].update();
        if (evt == ButtonEvent::NONE) continue;

        uint8_t catIdx = static_cast<uint8_t>(currentCategory);

        switch (evt) {
            case ButtonEvent::PRESS:
                sendAction(BTN_ACTIONS[catIdx][i]);
                break;

            case ButtonEvent::LONG_PRESS:
                // Appui long sur bouton 1 → retour à l'accueil DWIN
                if (i == 0) {
                    display.setPage(DWIN_PAGE_HOME);
                    Serial.println(F("NAV:HOME"));
                } else {
                    // Suffixe _LONG pour actions spéciales longues
                    char buf[48];
                    snprintf(buf, sizeof(buf), "%s_LONG",
                             BTN_ACTIONS[catIdx][i]);
                    sendAction(buf);
                }
                break;

            case ButtonEvent::DOUBLE_PRESS:
                // Suffixe _DBL pour actions double-appui
                char buf[48];
                snprintf(buf, sizeof(buf), "%s_DBL",
                         BTN_ACTIONS[catIdx][i]);
                sendAction(buf);
                break;

            default:
                break;
        }
    }
}

// ─────────────────────────────────────────────────────────────────────────────
// handleSerial() — Lecture et parsing des trames PC
// ─────────────────────────────────────────────────────────────────────────────
static void handleSerial() {
    while (Serial.available()) {
        char c = static_cast<char>(Serial.read());

        if (c == '\n') {
            // Fin de trame → traitement
            serialBuf[serialBufIdx] = '\0';

            if (strncmp(serialBuf, "CAT:", 4) == 0) {
                // Changement de catégorie demandé par le PC
                uint8_t catIdx = static_cast<uint8_t>(atoi(serialBuf + 4));
                if (catIdx < CATEGORY_COUNT) {
                    enterCategory(static_cast<Category>(catIdx));
                }
            } else {
                // Trame de données système
                if (FrameParser::parse(serialBuf, pcData)) {
                    lastPCReceiveTime = millis();
                    if (!pcConnected) {
                        pcConnected = true;
                        Serial.println(F("[StreamDeck] PC connecté"));
                    }
                }
            }

            serialBufIdx = 0;
        } else if (c != '\r') {
            // Accumulation (protection contre overflow)
            if (serialBufIdx < SERIAL_BUFFER_SIZE - 1) {
                serialBuf[serialBufIdx++] = c;
            } else {
                // Buffer plein → réinitialisation (trame corrompue)
                serialBufIdx = 0;
                Serial.println(F("[ERR] Buffer série overflow"));
            }
        }
    }
}

// ─────────────────────────────────────────────────────────────────────────────
// updateDisplay() — Mise à jour de l'écran DWIN avec les données PC
// ─────────────────────────────────────────────────────────────────────────────
static void updateDisplay() {
    if (!pcData.valid) return;

    // Titre morceau (toutes catégories)
    display.writeString(VP_TRACK_TITLE, pcData.trackTitle, 32);

    // HOME
    display.writeInt(VP_CPU_USAGE,  pcData.cpuUsage);
    display.writeInt(VP_RAM_USAGE,  static_cast<int16_t>(pcData.ramUsage * 10));
    display.writeInt(VP_MIC_STATUS, pcData.micMuted ? 1 : 0);

    // FOCUS
    char pomoStr[7];
    snprintf(pomoStr, sizeof(pomoStr), "%02d:%02d",
             pcData.pomoMinutes, pcData.pomoSeconds);
    display.writeString(VP_POMO_TIMER,   pomoStr, 6);
    display.writeInt(VP_POMO_SESSION,    pcData.pomoSession);
    display.writeInt(VP_DND_STATUS,      pcData.dndActive ? 1 : 0);

    // GAME
    display.writeInt(VP_FPS,        pcData.fps);
    display.writeInt(VP_OBS_STATUS, pcData.obsActive ? 1 : 0);

    // Invalidation pour éviter les re-écritures inutiles
    pcData.valid = false;
}

// ─────────────────────────────────────────────────────────────────────────────
// enterCategory() — Transition de catégorie avec persistance NVS
// ─────────────────────────────────────────────────────────────────────────────
static void enterCategory(Category cat) {
    if (cat == currentCategory) return;

    currentCategory = cat;

    // Mise à jour DWIN
    uint8_t page = static_cast<uint8_t>(cat) + 1; // Pages 1-4
    display.setPage(page);
    display.updatePotLabels(cat);

    // Mise à jour des valeurs potards sur la nouvelle page
    uint8_t potValues[POT_COUNT];
    for (uint8_t i = 0; i < POT_COUNT; ++i) {
        potValues[i] = pots[i].getValue();
    }
    display.updatePotValues(potValues);

    // Notification PC
    char buf[16];
    snprintf(buf, sizeof(buf), "CAT:%d",
             static_cast<uint8_t>(cat));
    Serial.println(buf);

    // Persistance NVS
    nvs.begin();
    nvs.saveCategory(cat);
    nvs.end();

    Serial.print(F("[StreamDeck] Catégorie → "));
    Serial.println(static_cast<uint8_t>(cat));
}

// ─────────────────────────────────────────────────────────────────────────────
// sendAction() — Envoi d'une action vers le PC
// ─────────────────────────────────────────────────────────────────────────────
static void sendAction(const char* action) {
    if (!action) return;
    char buf[64];
    snprintf(buf, sizeof(buf), "ACTION:%s", action);
    Serial.println(buf);
}

// ─────────────────────────────────────────────────────────────────────────────
// sendPotEvent() — Envoi d'un événement potentiomètre vers le PC
// ─────────────────────────────────────────────────────────────────────────────
static void sendPotEvent(uint8_t potIdx, uint8_t value) {
    uint8_t catIdx = static_cast<uint8_t>(currentCategory);
    char buf[48];
    snprintf(buf, sizeof(buf), "POT:%s:%d",
             POT_ACTIONS[catIdx][potIdx], value);
    Serial.println(buf);
}

// ─────────────────────────────────────────────────────────────────────────────
// checkPCConnection() — Détection déconnexion PC
// ─────────────────────────────────────────────────────────────────────────────
static void checkPCConnection() {
    if (!pcConnected) return;

    if ((millis() - lastPCReceiveTime) > PC_TIMEOUT_MS) {
        pcConnected = false;
        pcData.valid = false;
        Serial.println(F("[StreamDeck] PC déconnecté (timeout)"));

        // Affichage page d'accueil lors de la déconnexion
        display.setPage(DWIN_PAGE_HOME);
    }
}

// ─────────────────────────────────────────────────────────────────────────────
// initWatchdog() — Configuration du watchdog hardware
// ─────────────────────────────────────────────────────────────────────────────
static void initWatchdog() {
    esp_task_wdt_config_t wdtConfig = {
        .timeout_ms     = WDT_TIMEOUT_MS,
        .idle_core_mask = (1 << 0),  // Core 0
        .trigger_panic  = true        // Reset automatique si timeout
    };
    esp_task_wdt_reconfigure(&wdtConfig);
    esp_task_wdt_add(nullptr); // Enregistre la tâche courante (loop)
}

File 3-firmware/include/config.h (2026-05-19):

#pragma once
// =============================================================================
// config.h — Configuration centrale de Kore Deck
// Matériel : ESP32-S3-DevKitC-1 N16R8
// =============================================================================

#include <cstdint>

// -----------------------------------------------------------------------------
// SECTION 1 — GPIO POTENTIOMÈTRES (ADC1 obligatoire sur ESP32-S3)
// -----------------------------------------------------------------------------
constexpr uint8_t PIN_POT_1 = 4;   ///< ADC1_CH3 — Volume master / Zoom
constexpr uint8_t PIN_POT_2 = 5;   ///< ADC1_CH4 — Volume musique / Opacité
constexpr uint8_t PIN_POT_3 = 6;   ///< ADC1_CH5 — Luminosité / Rotation
constexpr uint8_t PIN_POT_4 = 7;   ///< ADC1_CH6 — Mic gain / Volume master

constexpr uint8_t POT_COUNT = 4;

// -----------------------------------------------------------------------------
// SECTION 2 — GPIO BOUTONS (Cherry MX, INPUT_PULLUP, actif à LOW)
// -----------------------------------------------------------------------------
constexpr uint8_t PIN_BTN[7] = {9, 8, 14, 13, 15, 12, 11};
constexpr uint8_t BTN_COUNT  = 7;

// -----------------------------------------------------------------------------
// SECTION 3 — UART DWIN (écran DMG96240C037_03W)
// -----------------------------------------------------------------------------
constexpr uint8_t  DWIN_UART_NUM = 1;        ///< UART1
constexpr uint8_t  DWIN_RX_PIN   = 16;       ///< ESP32-S3 RX ← DWIN TX (via BSS138)
constexpr uint8_t  DWIN_TX_PIN   = 17;       ///< ESP32-S3 TX → DWIN RX (via BSS138)
constexpr uint32_t DWIN_BAUD     = 115200;

// Pages DWIN
constexpr uint8_t DWIN_PAGE_HOME    = 0;
constexpr uint8_t DWIN_PAGE_CAT1    = 1;     ///< Home / Médias
constexpr uint8_t DWIN_PAGE_CAT2    = 2;     ///< 3D Making
constexpr uint8_t DWIN_PAGE_CAT3    = 3;     ///< Focus
constexpr uint8_t DWIN_PAGE_CAT4    = 4;     ///< Game

// Adresses VP (Variable Pointer) DGUS — ordre cohérent avec DGUS IDE
constexpr uint16_t VP_TRACK_TITLE   = 0x1010; ///< String 32 chars — titre morceau
constexpr uint16_t VP_CPU_USAGE     = 0x1030; ///< Int16 — CPU %
constexpr uint16_t VP_RAM_USAGE     = 0x1031; ///< Int16 — RAM % ×10
constexpr uint16_t VP_MIC_STATUS    = 0x1032; ///< Int16 0/1 — micro actif
constexpr uint16_t VP_POMO_TIMER    = 0x1080; ///< String 6 — "MM:SS"
constexpr uint16_t VP_POMO_SESSION  = 0x1086; ///< Int16 — numéro de session
constexpr uint16_t VP_DND_STATUS    = 0x1087; ///< Int16 0/1 — DND actif
constexpr uint16_t VP_FPS           = 0x1090; ///< Int16 — FPS jeu
constexpr uint16_t VP_OBS_STATUS    = 0x1092; ///< Int16 0/1 — OBS actif
constexpr uint16_t VP_POT_VAL[4]    = {0x2000, 0x2001, 0x2002, 0x2003}; ///< Int16 0-100
constexpr uint16_t VP_POT_LABEL[4]  = {0x2010, 0x2018, 0x2020, 0x2028}; ///< String 16

// -----------------------------------------------------------------------------
// SECTION 4 — FILTRAGE POTENTIOMÈTRES
// Technique : Oversampling + EMA + Hystérésis adaptative
// -----------------------------------------------------------------------------
constexpr uint8_t  POT_OVERSAMPLE_COUNT = 64;   ///< Lectures moyennées par sample
constexpr float    POT_EMA_ALPHA        = 0.08f; ///< Coefficient EMA (0=très lisse, 1=brut)
constexpr uint32_t POT_SAMPLE_PERIOD_MS = 20;    ///< Période d'échantillonnage (ms)

// Seuils d'hystérésis adaptative selon vitesse de variation
constexpr uint8_t HYST_FAST_THRESHOLD  = 1;  ///< dt < 50ms  → seuil 1%
constexpr uint8_t HYST_MED_THRESHOLD   = 2;  ///< dt < 200ms → seuil 2%
constexpr uint8_t HYST_SLOW_THRESHOLD  = 4;  ///< dt ≥ 200ms → seuil 4%
constexpr uint32_t HYST_FAST_DT_MS     = 50;
constexpr uint32_t HYST_MED_DT_MS      = 200;

// -----------------------------------------------------------------------------
// SECTION 5 — BOUTONS
// -----------------------------------------------------------------------------
constexpr uint32_t BTN_DEBOUNCE_MS       = 25;   ///< Anti-rebond hardware + software
constexpr uint32_t BTN_LONG_PRESS_MS     = 600;  ///< Durée appui long
constexpr uint32_t BTN_DOUBLE_PRESS_MS   = 300;  ///< Fenêtre double-appui

// -----------------------------------------------------------------------------
// SECTION 6 — COMMUNICATION PC (USB CDC natif)
// -----------------------------------------------------------------------------
constexpr uint32_t PC_SEND_INTERVAL_MS  = 100;   ///< Intervalle d'envoi des trames PC→ESP32
constexpr uint32_t PC_TIMEOUT_MS        = 3000;  ///< Délai avant détection déconnexion PC
constexpr uint16_t SERIAL_BUFFER_SIZE   = 512;

// -----------------------------------------------------------------------------
// SECTION 7 — WATCHDOG
// -----------------------------------------------------------------------------
constexpr uint32_t WDT_TIMEOUT_MS = 5000; ///< Reset si loop() bloque plus de 5s
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

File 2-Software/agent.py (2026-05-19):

# =============================================================================
# agent.py — Kore Deck — Agent PC v2.0 — Bridge WebSocket UI
# =============================================================================

import argparse, json, signal, sys, time, threading
from config          import config
from logger          import log, setup_logger
from serial_manager  import SerialManager
from system_monitor  import SystemMonitor
from spotify_monitor import SpotifyMonitor
from audio_manager   import AudioManager
from pomodoro        import PomodoroTimer
from action_executor import ActionExecutor
from ws_bridge       import WebSocketBridge


class KoreDeckAgent:
    def __init__(self) -> None:
        self._system    = SystemMonitor()
        self._spotify   = SpotifyMonitor()
        self._audio     = AudioManager()
        self._pomodoro  = PomodoroTimer()
        self._executor  = ActionExecutor(self._audio, self._pomodoro)
        self._serial    = SerialManager(on_line_received=self._on_line_received)
        self._bridge    = WebSocketBridge()
        self._bridge.on_config_update = self._on_config_update
        self._bridge.on_action        = self._on_ui_action
        self._current_category : int  = 0
        self._dnd_active       : bool = False
        self._obs_active       : bool = False
        self._last_send_time    = self._last_spotify_time = 0.0
        self._last_fps_time     = self._last_ws_push_time = 0.0
        self._cached_track : str = "Aucune lecture"
        self._cached_fps   : int = 0
        self._running    : bool = False
        self._stop_event = threading.Event()

    def start(self) -> None:
        log.info("=" * 60)
        log.info("Kore Deck — Agent PC v2.0")
        log.info(f"Port : {config.serial.port} | WS : ws://localhost:8765")
        log.info("=" * 60)
        self._bridge.start()
        self._serial.start()
        self._running = True
        self._bridge.send_agent_status("running")
        try:
            self._main_loop()
        except KeyboardInterrupt:
            log.info("Arrêt Ctrl+C")
        finally:
            self.stop()

    def stop(self) -> None:
        self._running = False
        self._bridge.send_agent_status("stopped")
        self._bridge.send_connection_status("disconnected")
        self._serial.stop()
        self._bridge.stop()
        log.info("Agent arrêté")

    def _main_loop(self) -> None:
        while self._running and not self._stop_event.is_set():
            now = time.monotonic()
            self._pomodoro.update()

            if now - self._last_spotify_time >= config.timing.spotify_interval:
                self._last_spotify_time = now
                self._cached_track = self._spotify.get_current_track()

            if now - self._last_fps_time >= config.timing.fps_interval:
                self._last_fps_time = now
                self._cached_fps = self._system.get_fps()

            if now - self._last_send_time >= config.timing.send_interval:
                self._last_send_time = now
                if self._serial.is_connected():
                    self._send_system_frame()
                    self._bridge.send_connection_status("connected")
                else:
                    self._bridge.send_connection_status("disconnected")

            if now - self._last_ws_push_time >= 0.2:
                self._last_ws_push_time = now
                if self._bridge.get_client_count() > 0:
                    self._push_stats_to_ui()

            time.sleep(0.005)

    def _push_stats_to_ui(self) -> None:
        cpu  = self._system.get_cpu_usage()
        ram  = self._system.get_ram_usage()
        mins, secs = self._pomodoro.get_remaining()
        sess = self._pomodoro.get_session_count()
        track = self._cached_track
        artist = ""
        if " - " in track:
            parts = track.split(" - ", 1)
            artist, track = parts[0], parts[1]
        self._bridge.send_stats({
            "cpu": cpu, "ram": ram, "fps": self._cached_fps,
            "mic": self._audio.is_mic_muted(),
            "dnd": self._dnd_active, "obs": self._obs_active,
            "track": f"{artist} - {track}" if artist else track,
            "pomo": {"min": mins, "sec": secs, "session": sess,
                     "running": self._pomodoro.is_running()},
        })

    def _send_system_frame(self) -> None:
        cpu  = self._system.get_cpu_usage()
        ram  = self._system.get_ram_usage()
        mins, secs = self._pomodoro.get_remaining()
        sess = self._pomodoro.get_session_count()
        frame = (f"CPU:{cpu}|RAM:{ram:.1f}|TRACK:{self._cached_track}"
                 f"|FPS:{self._cached_fps}"
                 f"|MIC:{1 if self._audio.is_mic_muted() else 0}"
                 f"|DND:{1 if self._dnd_active else 0}"
                 f"|OBS:{1 if self._obs_active else 0}"
                 f"|POMO:{mins}:{secs}:{sess}")
        self._serial.send(frame)

    def _on_line_received(self, line: str) -> None:
        log.debug(f"← ESP32 : {line}")
        if line.startswith("ACTION:"):
            self._executor.execute_action(line[7:])
        elif line.startswith("POT:"):
            parts = line[4:].split(":")
            if len(parts) == 2:
                try: self._executor.execute_pot(parts[0], int(parts[1]))
                except ValueError: pass
        elif line.startswith("CAT:"):
            try: self._current_category = int(line[4:])
            except ValueError: pass
        elif line == "READY":
            log.info("ESP32 prêt")
            self._bridge.send_connection_status("connected")
        elif line == "PING":
            pass

    def _on_config_update(self, data: dict) -> None:
        log.info(f"Hot-reload config depuis UI")

    def _on_ui_action(self, action: str) -> None:
        log.info(f"Action UI : {action}")
        self._executor.execute_action(action)


def main() -> None:
    parser = argparse.ArgumentParser(description="Kore Deck — Agent PC v2.0")
    parser.add_argument("--port",  type=str, default=None)
    parser.add_argument("--debug", action="store_true")
    args = parser.parse_args()
    if args.port:  config.serial.port = args.port
    if args.debug: setup_logger(level="DEBUG")

    agent = KoreDeckAgent()
    def _sig(sig, frame):
        agent.stop(); sys.exit(0)
    signal.signal(signal.SIGINT, _sig)
    signal.signal(signal.SIGTERM, _sig)
    agent.start()

if __name__ == "__main__":
    main()

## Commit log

2026-05-15 Adding pcb, Gerbers Files...
    [BOM_PCB.csv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]
2026-05-19 feat: Kore Deck v2.0 — App integration, Maj Software, Maj Firmware, Maj README
